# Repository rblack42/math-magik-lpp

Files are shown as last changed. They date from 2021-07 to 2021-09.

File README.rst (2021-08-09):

Math Magik LPP (v0.1.0)
#######################
:Author:    Roie R. Black
:Email:     roie.black@gmail.com
:Docs:      https://rblack42.github.io/math-magik-lpp

..  start-badges

.. list-table::
    :stub-columns: 1

    * - tests
      - | 



..  image:: rst/_static/lpp.gif
    :align: center
    :width: 600

.. end-badges

If you are visiting this link after reading my article *Designing an Indoor
Model Using OpenSCAD* in the 2021 edition of the NFFS Symposium, welcome!

This site is a work in progress. If you are interested in trying ano of this
project, please contact me at the email address above and I will be glad tro
provide assistance in getthing things running.

Here you will find updated documentation on building the *math-magik-lpp
*Limited Pennyplane* model, with corrections to equations and figures from the
symposium article.

More information on analyzing this model can be found on the companion website
at https://rblack42.github.io/math-magik

The project documentation is available at the link above. There you will find
material detailing the *OpenSCAD* code developed to support this project.

All code, both *OpenSCAD* and Python code, can be found on my github account:

    * https://github.com/rblack42/math-magik
    * https://github.com/rblack42/math-magik-lpp

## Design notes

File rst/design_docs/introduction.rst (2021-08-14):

Introduction
************

In this section you fill find listings of all |OSC| code used to generate the
|MM| |LPP| model. All documentation pages were generated automatically from the
current code in this project.

This documentation includes code blocks showing the actual |OSC| code created
for this model.

..	note::

    You *could* copy and paste these code blocks directly from these web pages,
    but that would be silly. Instead, go to the project site on |GH|_ and you
    can see everything I have generated for this project, uncluding the |OSC|
    code and supporting |PY| code.

The design code documentation is organized in the same way as the |OSC| files
themselves. Each part or assembly has its own directory and there is one
documentation page describing all of the files within that directory. The
pattern of the documentation is described below.

File Naming Convention
======================

I am using a simple naming convention for this project. All files used by |OSC|
to generate the complete model end with a **.scad** extension. Each part of
assembly is defined within a directory with that part or assembly name. Inside
that directory you will find a file with the same name as the directory, and
the **.scad** extension. This design file can be loaded into |OSC| and it will
generate that part or assembly for you to examine.

If and dimensions are needed to create a component, thse data values will be
located in files with names that look like this: **name_data.scad**. There are
two data files that do not follow this convention, both in the tip level code
directory: **constraints.scad** defines dimensions from the AMA rules for this
class, and **materials.scad** contains basic material dimensions.used in the
design.

Finally, positioning data needed t properly place each part or assembly in a
larger assembly are named with a pattern that looks like this:
**name_pos.scad**.

Design Notes
============

Information needed to describe how this component was designed will be
presented here.

Design File
===========

The code for the part or assembly is shown here. The caption at the top of each
listing indicates where in the actual code directory tree this file can be
located.

Data Files
==========

If data is needed to create this component, the data files used are shown next.
These files *include* other |OSC| files as needed to fully define all values
defined.

Components
==========

Assemblies gather other components together to create a larger component. In
the design file, we *use* these component files so we can refer to the needed
part or assembly. These will be placed properly using position data shown in
the next section. (This section will not be present for part documentation).

The list of components needed for the current assembly is shown as links that
will take you to the documentation for that component.

Component Position Data
=======================

All components needed to create the current assembly need to be oriented
properly in the new assembly's coordinate system. I created a simple **align**
function that will place each component using translations and rotations as
needed. The position data for each component is a vector with six values, three
for translations, and three for rotations. (This section will not be present
for part documentation)

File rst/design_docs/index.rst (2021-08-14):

assembly: math_magik_lpp
########################

..  include::  design_notes.rst

assembly Design File
********************

..  literalinclude::  ../../scad/math_magik_lpp.scad
    :linenos:
    :caption: math_magik_lpp.scad

Component Data File(s)
**********************

..  literalinclude::  ../../scad/math_magik_lpp_data.scad
    :linenos:
    :caption: math_magik_lpp_data.scad

..  literalinclude::  ../../scad/constraints.scad
    :linenos:
    :caption: constraints.scad

..  literalinclude::  ../../scad/materials.scad
    :linenos:
    :caption: materials.scad

Components
**********

..  toctree::
    :maxdepth: 1

    prop/index
    stab/index
    fuselage/index
    rubber_motor/index
    wing/index

Component Position File
***********************

..  literalinclude::  ../../scad/math_magik_lpp_pos.scad
    :linenos:
    :caption: math_magik_lpp_pos.scad

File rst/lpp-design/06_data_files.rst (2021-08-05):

Data Files
##########

We need to define dimensions for all the parts that make up the model. We also
need to define placement values that place each part or assembly in the proper
position in the model. Using |OSC|, we will define parts individually, then
assemble parts into assemblies. These may be further combined to produce the
final model. Al l of that means we need to set up these constants and do some
calculations to get things right.

Rather than place dimensions directly in the files where they are needed, I
elected to factor them out into separate data files that get included as
needed. The scheme I came up with to organize these data files is outlined
here.

Part Data Files
***************

Within each part directory (no subdirectories in these), the part data file
contains values needed to create the part. These data files may include other
data files as needed to fully define the part. For that reason, all data items
include the part name to avois conflicts in other places.

Assembly Data Files
*******************

When combining parts (or other assemblies) we need data that helps properly
place all components to create the assembly. Data needed for assemblies is
located in an assembly data file.

Position Data Files
*******************

In order to facilitate design analysis, all positioning data items are located
in position data files. These are only located in assembly directories.

Naming Data
***********

All data items have a distinct name. As much as possible, no "bare" numbers
should be found in shape design files. Instead, we include the necessary data
files to create each component.

Hopefully, changes to the design can be made by adjusting data item values.
Changes in the shape design files should not be needed, unless you are changing
that shape in some fundamental way.

Data Catalog
************

..	todo::

    Add a catalog of all defined data. This will be generated using a Python
    script that scans all data files.

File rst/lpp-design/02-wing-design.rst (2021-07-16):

Wing Design
###########

I decided to make this wing fairly simple. Basically it uses a constant chord
with rounded tips. The wing uses a conventional flat center section, with the
tips raised to provide the needed stability. Here is the general layout:

..  tikz::
    :libs:  arrows, calc

    \draw[ultra thick]  (0,0) -- (8,0) -- (8,3);
    \draw[ultra thick]  (8,3) arc[
    start angle=0,
    end angle=90,
    x radius=2,
    y radius=2] -- (0,5);

    \draw[thin] (0,5) -- (0,5.5) node[above] {$ c_l $};
    \draw[thin] (0,0) -- (0,5);
    \draw[thin,->] (0,0) -- (0,-0.5) node [below] {$x$};

    \draw[thin] (4,5) -- (4,0) node[below] {$y_t$};

    \draw[thin] (6,5) -- (6,0) node[below] {$y_a$};
    \draw[thin] (6,3) -- (8,3);
    \draw[thin,->] (8,0) -- (8.5,0) node[right] {$y$};

    \draw[thin] (0,0) -- (-0.5,0);
    \draw[thin] (0,5) -- (-0.5,5);
    \draw[thin,<->] (-0.25,0) -- node[left] {$C$}(-0.25,5);

    \draw[thin,->] (6,3) --node[above left] {$r_t$}  +(45:2);

    \draw[thin] (8,3.5) -- (8,5.5);
    \draw[thin, <->] (0,5.25) -- node[above] {$S/2$}(8,5.25);

The center section is a simple rectangular structure with a constant chord. The
span of this section is a design decision. Setting this dimension will have an
effect on the span of the tips, since the total projected wing span is fixed by
the rule constraints. I decoded to set up the dimensions for the center section
in a data file that will be placed in a **wing** subdirectory under the main
design directory

..  literalinclude::    ../../scad/wing/wing_data.scad
    :language: c
    :caption:   math-magik-lpp/scad/wing/wing_data.scad
    :linenos:

Notice that we *include* the **constraints.data** file so we can refer to
constants defined there. The path to that file shows that it is in the
directory above the **wing** directory (the main design directory).

For reference, here are the named constants we are using and the symbols from
the figure above:

..  csv-table::
    :header: constant, figure

    center_span, :math:`2 * y_t`
    chord, :math:`c`
    tip_radius, :math:`r_t`

Wing Ribs
*********

I decided to use a simple circular arc airfoil for this design. The arc is
defined by specifying the *camber* as a percentage of the chord. Figuring out
the actual arc radius involves a bit of math, byyt a nice Python tool called
*SymPy* makes this pretty easy (see the appendix for details). The formula for
the arc is given below:

..  math::

    r = \frac{c^2}{8t} + \frac{t}{2}

Where :math:`c` is the airfoil chord, and :math:`t` is the thickness. This last
value is simply calculated form the chord and camber (:math:`T`):

..  math::

    t = \frac{Tc}{100}

There are two ways to build this rib. One way involves bending a strip of wood
over a form to produce the rib. The second way uses a template to cut the rib
out of sheet stock. In the first case, there is a problem you might not notice
in building a real airplane. Suppose you want to make the front and rear spars
out of simple square stock, and you want to mage the rib using the same size as
the spars. If you slice off the arc at the leading and trailing edges, the
height of the rib at both points is actually larger than the spar sizes. This
is easy to see using |OSC|, which led me to use the template approach.

If you use a template, the arc is used to make a first cut, then the template
is slid down by the spar size and a second cut produces a rib with exactly the
right height on both ends. The problem is finding a way to create this rib
using |OSC| code.

Template Rib Library Module
===========================

I ended up using the *linear extrude* feature of |OSC| to create a general rib
shape. This |OSC| *module* is our first *library module*. The parameters of
this module allow us to create ribs as needed for any design.

The outline of the rib is a 2D figure produced using the above formulas to
calculate the radius of the arc we need. The outline is formed by creating two
circles, shifted by the height of the rib. These circles are trimmed using 2D
square shapes.  Finally the outline is extruded to generate the 3D rib.

..  literalinclude::    ../../MMlib/circle_template_rib.scad
    :language: c
    :caption: MMlib/circle-template-rib.scad
    :linenos:

This is a bit scary on first look, but line by line it should make sense. The
|OSC| *module* is a reusable chunk of code we will need when generating our
actual ribs. The parameters we need to supply are these:

    * chord - the trimmed length of the rib (not including the spars)
    * camber - the thickness as a percentage of the chord
    * height - basically the height of the leading and trailing edge spars
    * thickness - the thickness of the sheet we will use to form the ribs

Notice that there is code after the *module8 definition that serves to display
the shape if we load this *library module* file in |OSC|. This code will not be
run when we generate actual ribs using this module. This technique is handy
when debugging code.

It is important to note the position of the rib in the coordinate system. The
origin of this system is sitting in the center of the leading edge, with the
bottom of thr rib sitting on the **X-Y** plane. The rib is oriented so the
**Z** is "up". The **Z** axis runs through the center of the rib. We will need
this information when we place ribs in the actual design.

Generating Wing Ribs
====================

Now, we can create a rib *module* for wing ribs. All we need to do here is set
the correct values for the parameters:

..  literalinclude::    ../../scad/wing/center/rib/rib.scad
    :language: c
    :caption:   math-magik-lpp/wing/center/rib/rib.scad
    :linenos:

We will use five of these ribs, each properly positioned to form the wing
center section.

Here is the basic rib shape, ready for placement in the wing:

..  figure:: wing-rib.png
    :align: center
    :width: 500

Leading and Trailing Edges
**************************

The leading and trailing edge spars are something of a letdown! They are simple
square spars of a defined length. Again, it is handy to generate a *library
module* for a basic square spar.

..  literalinclude::    ../../MMlib/square_spar.scad
    :language: c
    :caption:   MMlib/square_spar.scad
    :linenos:

The spars created using this module are centered along the **Y** axis, again
sitting on the **X-Y** plane. This will be convenient for assembling the wing
center section.

..  figure:: wing-spar.png
    :align: center
    :width: 500

Assembling the Center Section
*****************************

We have defined the parts needed to build the center section frame. All we need
to do is place the parts in the right positions. We will let |OSC| do the
calculations needed for this step.

We need to decide how to organize these parts before building this section. WHile it is possible to do this all in one file, doing the analytical work to predict the weight and balance data will be more difficult if we do that. Instead, I decided to create directories for each part, and set up placement data files that control where each part sits in the final model. Although this creates a lot of directories, it keeps things more organized as we generate additional files during the analysis phase.

For the wing center section, we will need eight new direcroties, five for the ribs, one each for leading and trailing edges, and a final one for the covering.

The ribs and spars are created using our library modulae. We will add a placement data file in each part directoriy that defines exactly where the part sits in the assembly we are creating.

..  note::

    This plaement is not where the part sits in the final model. We will move assemblies into place as we build the final model.

Let's look at the rib at the left side (pilot's view") of the center section.

..
..  literalinclude::    ../../scad/wing/center/center.scad
    :language: c
    :caption: wing/center/center.scad
    :linenos:

..  note::

    This code is set up to color the material. The **colors.scad** file
    containg a number of useful color definitions was found on the Internet,
    and I added a color for Balsa. The eliminates the ugly green color that is
    generated by default when |OSC| creates images.

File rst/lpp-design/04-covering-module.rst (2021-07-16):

Building the Covering Module
############################

The covering module will be constructed as a Python class, allowing for
different rib sections, and wing outlines. In time, this code will be extended
to cover a variety of models.

Here is our start:

..

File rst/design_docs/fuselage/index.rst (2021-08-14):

assembly: fuselage
##################

..  include::  design_notes.rst

assembly Design File
********************

..  literalinclude::  ../../../scad/fuselage/fuselage.scad
    :linenos:
    :caption: fuselage/fuselage.scad

Component Data File(s)
**********************

..  literalinclude::  ../../../scad/fuselage/fuselage_data.scad
    :linenos:
    :caption: fuselage/fuselage_data.scad

Components
**********

..  toctree::
    :maxdepth: 1

    rear_hook/index
    thrust_bearing/index
    fin/index
    tail_boom/index
    wing_post/index
    stab_post/index
    motor_stick/index

Component Position File
***********************

..  literalinclude::  ../../../scad/fuselage/fuselage_pos.scad
    :linenos:
    :caption: fuselage/fuselage_pos.scad

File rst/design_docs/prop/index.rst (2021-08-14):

assembly: prop
##############

..  include::  design_notes.rst

assembly Design File
********************

..  literalinclude::  ../../../scad/prop/prop.scad
    :linenos:
    :caption: prop/prop.scad

Component Data File(s)
**********************

..  literalinclude::  ../../../scad/prop/prop_data.scad
    :linenos:
    :caption: prop/prop_data.scad

Components
**********

..  toctree::
    :maxdepth: 1

    blade/index
    spar/index
    wire_shaft/index

Component Position File
***********************

..  literalinclude::  ../../../scad/prop/prop_pos.scad
    :linenos:
    :caption: prop/prop_pos.scad

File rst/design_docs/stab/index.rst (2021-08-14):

assembly: stab
##############

..  include::  design_notes.rst

assembly Design File
********************

..  literalinclude::  ../../../scad/stab/stab.scad
    :linenos:
    :caption: stab/stab.scad

Component Data File(s)
**********************

..  literalinclude::  ../../../scad/stab/stab_data.scad
    :linenos:
    :caption: stab/stab_data.scad

Components
**********

..  toctree::
    :maxdepth: 1

    center/index
    left_tip/index
    stab_mount/index
    right_tip/index

Component Position File
***********************

..  literalinclude::  ../../../scad/stab/stab_pos.scad
    :linenos:
    :caption: stab/stab_pos.scad

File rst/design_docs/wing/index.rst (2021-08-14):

assembly: wing
##############

..  include::  design_notes.rst

assembly Design File
********************

..  literalinclude::  ../../../scad/wing/wing.scad
    :linenos:
    :caption: wing/wing.scad

Component Data File(s)
**********************

..  literalinclude::  ../../../scad/wing/wing_data.scad
    :linenos:
    :caption: wing/wing_data.scad

Components
**********

..  toctree::
    :maxdepth: 1

    center/index
    left_tip/index
    right_tip/index
    Wing_mount/index

Component Position File
***********************

..  literalinclude::  ../../../scad/wing/wing_pos.scad
    :linenos:
    :caption: wing/wing_pos.scad

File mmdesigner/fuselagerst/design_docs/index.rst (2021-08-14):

assembly: fuselage
##################

This assembly is created with the following file:

..  literalinclude::  ../../scad/fuselage/fuselage.scad
    :linenos:
    :caption: fuselage/fuselage.scad

Component Data File(s)
**********************

..  literalinclude::  ../scad/fuselage/fuselage_data.scad

Components
**********

..  toctree::
    :maxdepth: 1

    rear_hook/index
    thrust_bearing/index
    fin/index
    tail_boom/index
    fin_post/index
    wing_post/index
    stab_post/index
    motor_stick/index

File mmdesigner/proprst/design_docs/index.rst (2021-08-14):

assembly: prop
##############

This assembly is created with the following file:

..  literalinclude::  ../../scad/prop/prop.scad
    :linenos:
    :caption: prop/prop.scad

Component Data File(s)
**********************

..  literalinclude::  ../scad/prop/prop_data.scad

Components
**********

..  toctree::
    :maxdepth: 1

    blade/index
    spar/index
    wire_shaft/index

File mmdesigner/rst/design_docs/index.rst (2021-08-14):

assembly: math_magik_lpp
########################

This assembly is created with the following file:

..  literalinclude::  scad/math_magik_lpp.scad
    :linenos:
    :caption: math_magik_lpp.scad

Component Data File(s)
**********************

..  literalinclude::  ../scad/math_magik_lpp_data.scad

..  literalinclude::  ../scad/constraints.scad

..  literalinclude::  ../scad/materials.scad

Components
**********

..  toctree::
    :maxdepth: 1

    prop/index
    stab/index
    fuselage/index
    rubber_motor/index
    wing/index

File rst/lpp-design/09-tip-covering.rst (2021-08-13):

Tip Covering Logic
##################

Covering the center section of the wing and stab is a snap. That covering is
actually a simple slice out of a very thin cylinder since we are using
circular arc airfoils. I chose the generate the points on a grid that covers
the center section and use the *Function Grapher* logic created by `Justin
lin`_ to generate the actual covering shape.

The tips are another matter. If we keep the outer ribs of the center section
vertical and raise the wing tip up to form the dihedral, the inner edge of the
tip covering is not a straight line. Mathematically, it is a piece of an ellipse
formed by cutting a cylinder with an angled plane. We can extract the
coordinates of the outer edge of the center section covering and use those points
as our starting point for the tip covering. However, we need to account for the
dihedral angle we will be using and adjust those points to find the correct
starting points for the tip covering. (Remember, there is no actual rib here.

Tip Airfoil
***********

The tip has no ribs, only the tip outline as a structure. If we cover an actual
model with this structure, something modelers typically do by building the wing
flat, then the covering assumes some shape other than out circular arc as we
move toward the tip. The actual height of this shape tapers off to zero as we
approach the tip.

Here is a basic diagram showing the tip design:

..  tikz::
    :libs: calc, intersections

    \makeatletter
    \newcommand{\gettikzxy}[3]{%
        \tikz@scan@one@point\pgfutil@firstofone#1\relax
        \edef#2{\the\pgf@x}%
        \edef#3{\the\pgf@y}%
    }
    \makeatother

    \coordinate (o) at (0,0); % name the origin
    \coordinate (le) at (5,5); % inner leading edge
    \coordinate (te) at (5,0); % inner trailing edge
    \coordinate (s) at (2,5); % start of rib arc
    \coordinate (c) at (2,3); % center of rib arc
    \coordinate (t) at (0,3);  % top of outer rib

    % draw dihedral angle
    \draw[thick] (te) -- (o) -- (t);
    \draw[thick] (s) -- (le);
    \draw[thick, name path=arc] (2,5) arc (90:180:2);
    \draw[thin] (t) --  (0,6);
    \draw[thin, name path=grid] (0,4.5) -- (5,4.5);
    \draw[thin] (t) -- (c);
    \path [name intersections={of=arc and grid, by=E}];
    \draw[black,fill] (E) circle [radius=0.05];
    \gettikzxy{(E)}{\dx}{\dy}
    \draw [thin] (E) -- (\dx,1.5);
    \draw[thin, ->] (3,5.5) -- (3,5);
    \draw[thin, ->] (3,4) node[below]{$x$} -- (3,4.5) ;
    \draw[thin, ->] (-0.25,2) -- (0,2);
    \draw[thin, <-] (\dx,2) -- (1.2,2) node [right] {$\delta$};
    \draw[thin] (2,3) -- node [left] {$r$} (E) node [above] {$p$};
    \draw [thin] (s) -- (-0.75,5);
    \draw[thin, <->] (-0.5,5) -- node [left] {$C$} (-0.5,0);
    \draw[thin] (-0.75,0) -- (0,0);

In this figure, we are going to pick points on the outer part of the tip, along
the arc and the outer tip rib, that represent the intersection of a vertical
plane parallel to the **Y** axis drawn from the inner tip rib points to the
outer tip structure. We calculate the **Y** offset of the tip at the
intersection ($\delta$ in the figure above) and draw a straight 3D line between
the inner point and this outer tip structure. We will distribute points along
this line using the number of points selected in the **Y** direction for our
grid.

Since there are no supporting ribs along the tip span, I am going to assume
that the covering can be modeled as a set of straight lines from a point on the
center section outer rib to the tip outline. The selected points on the outline
will be chosen so that these tip covering lines are all parallel to the wing
axis (**Y**). This is not "real" in any sense, but should look fine visually,
and give us something close to right in weight and balance calculations.
Furthermore, the tip covering grid will need involves far fewer data points
than we might need with other ideas.

It is important to note that there will be visual problems as the covering
approaches the circular arc. The generated covering uses straight lines between
data points, and that means the tip outline will not be covered correctly. The
fewer the points we set up in the chord wise direction, the worse things will
look.

iWe are generating the grid for our covering using evenly distributed points
along the span and chord. In that code **x**, and **y** range from zero to one
and must be scaled to determine physical values.

The equations needed for calculating the coordinates of our tip grid point
(point **p** in the figure) are given here:

..  math::

    x_p = x * C

    y_p = span - \delta

    z_p =  tip_spar_size

We can determine $\delta$ using the equation of the circular arc centered as
shown in the figure:

..  mathcode::
   import sympy

   x,r,delta,c = sympy.symbols('x r delta c')
   eq1 = (r - delta)**2 + (r - x)**2 - r**2
   sol = sympy.solve(eq1, delta)
   sol[0]

And here is an image showing the grid on the wing tip:

Virtual Tip Rib
***************

There is no physical rib at the tip inner line. Instead the covering attaches
to the outer center section rib. When the tip is placed in its final position,
raised up to form the dihedral, the inner most edge of the tip covering must be
trimmed off to join nicely. Actually, we can use those center section rib
elevation values to form the correct starting points for the tip covering. The
calculations are pretty simple:

..  math::

    x_0 = x_c

    y_y = - z_c \sin{\theta}

    z_o = z_c \cos{\theta}

Here, the **0** subscript refers to the tip coordinate values at the "virtual
starting rib point, and **c** refers to the point values on the outer center
section rib. $\theta$ is the dihedral angle.

Python Covering Code
********************

All of the calculations needed to generate covering grids are included in the
**Covering.py** code file. This code creates a **covering.scad** file that cna
be *included* in other |OSC| files to generate the actual covering surface.

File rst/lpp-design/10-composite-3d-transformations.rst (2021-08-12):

Composite 3D Transformations
############################

In calculating the center of gravity for our model, we need to track how the center of mass for a given part moves as we align it into an assembly, them aligh an assembly into the final model. Qw uaw simple translation and rotation transformations to get our parts aligned as we wish in our design.

Translation Transformations
***************************

Mathematically, we can describe any transformation by setting up a
*transformation matcix* and using that matrix to calculate the effect of a
translation transformation.

Suppose we want to translate a shape using these distances in each coordinate
direction: $D_x$, $D_y$, and $D_z$. If we define a point, $P_0$ using three
positions: $P_x$, $O_y$, and $P_z$, then the translated point can be defined using
matrix multiplication:

..	math::

	T_1 = \left[\begin{matrix}1&0&0&0\\
		0&1&0&0 \\
		0&0&1&0 \\
		D_x&D_y&D_z&1\end{matrix}\right]

The position is given using a vector:

..	math::

	P_0 = \left[\begin{matrix}P_x&P_y&P_z&1\end{matrix}\right]

Rotations
*********

First, we rotate arount the **x** axis by an angle $\theta$:

..  math::

	R_x = \left[\begin{matrix}1&0&0&0\\
		0&\cos{\theta}&\sin{\theta}&0 \\
		0&-\sin{\theta}&\cos{\theta}&0 \\
		0&0&0&1\end{matrix}\right]

	R_y = \left[\begin{matrix} \cos{\beta}&0&-\sin{\beta}&0\\
		0&1&0&0 \\
		\sin{\beta}&0&\cos{\beta}&0 \\
		0&0&0&1\end{matrix}\right]

	R_z = \left[\begin{matrix}\cos{\zeta}&-\sin{\zeta}&0&0\\
		\sin{\zeta}&\cos{\zeta}&0&0 \\
		0&0&1&0 \\
		0&0&0&1\end{matrix}\right]

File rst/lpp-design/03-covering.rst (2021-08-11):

Generating Covering
###################

Building the basic framework of an indoor model airplane with |OSC| is fairly
easy. Covering is another matter entirely. There is no simple way to generate a
thin film that covers flying surface frameworks using just |OSC|. We need to
take another approach.

Since we are using math to figure out a lot of this design, let's see what we
can do if we think this through.

STL Files
*********

|OSC| is a 3D solid modeling tool most often used in generating 3D printer
products. Part of that generation process involves converting the 3D objects
into |STL| files. These files are then post-processed to generate input data
files for the 3D printer. An |STL| file is a (long) list of triangles that
"wrap" the surface in question. These triangles are all connected in such a way
that the surface is called water tight, meaning there are no gaps anywhere. If
the triangles are big, the surface will not resemble the original shape very
much, but if we make them tiny, he resulting surface will look very good. What
this means is that our entire model can be reduced to a giant list of triangles
surrounding the structure. The closer the points on these triangles are to each
other, the closer our approximation to the real shape gets.

Typically, indoor models are covered using a very thin film. Suppose we
generate a grid of points that sit on the surface we want to represent our
covering. The grid will represent a set of quadrilateral (four point) areas  on
that surface. We can draw a diagonal across each quad surface to produce two
triangles. Then we "extrude" these upward a tiny amount to represent a chunk of
film.This is exactly what an |STL| file looks like.

The thickness of the film is not important here. We only need it to be thick
enough to be visible in |OSC|. Traditionally, film weights are given in terms
of surface area, not volume. As long as we know what thickness we have set up
for our digital film, we can transform the volume we calculate for our covering
into a surface area and get the weight we need to weight and balance
calculations.

Function Grapher
****************

Suppose you can build a mathematical function describing the covering surface
you need:

..	math::

	Surface height = f(x,y)

Our challenge is to create a two-dimensional matrix of points covering each
segment of a flying surface. The surface function will tell us the height of
the surface at each point. Each point will be recorded using the **X**, **Y**,
and **Z** (height) values for the covering surface.  Python can write these
points out so that |OSC| can read the file produced.  Sounds simple enough for
a Python programmer.

`Justin Lin`_ created a tool for displaying a 3D function, input as a
collection of 3D points, using the **polyhedron** tool in |OSC|. His function
takes the rectangular array of 3D *X-Y-Z* points and extrudes them to create a
surface with a user defined thickness in the **Z** direction. Justin has a
library that uses this scheme on his website, and I started off by extracting
just part of that his for use in this project. This scheme is suitable for
indoor models, but will not work for more general model building, so I plan on
replacing this code at a later time.

Generating Covering Points
**************************

The challenge in using this approach is generating the matrix of points. I
elected to do this work in Python, and created a function that generates the
needed point array we can use for the covering.

The basic scheme used involved nested loops that create the grid. If we have **nx** points in the **X** direction, and **ny** points in the **Y** idirection, the loop setup looks like this:

..  code-block::    python

    dx = chord / nx
    dy = span / ny
    points = []
    for i in range(ny+1):
        y = i * dy
        xpoints = []
        for j in range(nx+1):
            x = j * dx
            z = surface_height(x,y)
            xpoints.append([x,y,z])
        points.append(xpoints)

Here, we are creating our surface data matrix as a "list of lists", which is
how you do this in Python.

Let's look at the rib height function we will use for the wing and stab center
sections.

Rib Height
==========

Here is our basic geometry:

..  tikz::
    :libs:  arrows, calc

    \draw(0,0) -- (7,0);
    \draw[thick](3.5,0) -> node[above] {r} ++(45:2.5) coordinate (p1);
    \draw(3.5,0) -- ++(135:2.5) coordinate (p2);
    \draw(3.5,0) -- (3.5,3);
    \draw[ultra thick] (p1) arc (45:135:2.5);
    \draw (4.5,0) arc (0:45:1);
    \draw (p1) -- (p2);
    \node[right] at (p1) {te};
    \node[left] at (p2) {le};
    \coordinate (angle_label) at ($ (3.5,0) + (22.5:1.2) $);
    \node at (angle_label) {$\alpha$};
    \coordinate (p3) at ($(p1) + (0,1.5) $);
    \coordinate (p4) at ($ (p2) + (0,1.5) $);
    \draw[<->] (p3) -- node[above] {C} (p4);

From this figure, we can generate two equations:

..  math::

    t = r - r sin(\alpha)

    C = 2 r cos(\alpha)

Here **C** is the rib chord and **t** is the rib thickness. We need to figure
out the radius, **r** and the angle :math`\alpha`.

Rather than doing this manually, let's introduce Python SymPy_, a neat tool you
wish you had back in your school days.

Here is a piece of code that will give up the results we are after:

..  code-block:: python

   import sympy

    r,c,t,alpha = \
      sympy.symbols('r c t alpha')

    eq1 = 2 * r * sympy.cos(alpha) - c
    eq2 = r - r * sympy.sin(alpha) - t
    sol = sympy.solve([eq1,eq2],[r,alpha])
    print(sol)

SymPy_ requires that you name your equations, and set them up as expressions
that evaluate to zero. So we move the left-hand side of each equation over to
the right and come up with some usable name.

The neat feature is the line where we solve these two equations for the two
unknowns. SymPy_ will produce the solutions we are after!

Here they are, nicely formatted:

..  mathcode::

    import sympy
    r,c,t,alpha = \
      sympy.symbols('r c t alpha')

    eq1 = 2 * r * sympy.cos(alpha) - c
    eq2 = r - r * sympy.sin(alpha) - t
    sol = sympy.solve([eq1,eq2],[r,alpha])
    sol[1]

The first solution gives us the arc radius, the second on gives :math:`\alpha`.

Let's check these equations out with a little Python code.

..  code-block::    python

    import math

    c = 5.0       # chord
    camber = 5.0  # percent of c

    t = camber * c
    r = c**2/(8*t) + t/2
    alpha = math.acos(4*c*t'(c**2 + 4*t**2)) * 180.0/math.pi
    print(r, alpha)

Here is what we get:

..  mathcode::

    import math

    c = 5.0       # chord
    camber = 5.0  # percent of c

    t = camber * c
    r = c**2/(8*t) + t/2
    alpha = math.acos(4*c*t/(c**2 + 4*t**2)) * 180/math.pi
    (r,alpha)

As  check, let's calculate the thickness using these values:

..  code-block:: python

    thickness = r - r * math.sin(alpha * math.pi/180.0)
    print(thickness)

..  mathcode::

    thickness = r - r * math.sin(alpha * math.pi/180.0)
    thickness

That is what we expect, so things look fine.

Rib Height
==========

To generate the height function needed to create our covering data array, we
need a bit of geometry. Since we are using a circular arc airfoil, the figure
below show basically what we need to generate the function:

..  tikz::
    :libs:  arrows, calc

    \newcommand{\tikzAngleOfLine}{\tikz@AngleOfLine}
    \def\tikz@AngleOfLine(#1)(#2)#3{%
    \pgfmathanglebetweenpoints{%
    \pgfpointanchor{#1}{center}}{%
    \pgfpointanchor{#2}{center}}
    \pgfmathsetmacro{#3}{\pgfmathresult}%
    }

    \coordinate (o) at (0,0);
    \coordinate (c) at ($(o)+(-45:2)$);
    \coordinate (e) at ($(c)+(45:2)$);
    \coordinate (t) at ($(c)+(67.5:2)$);
    \coordinate (p) at ($(c)+(67.5,2)$);
    \coordinate (m) at ($(o)!0.5!(e)$);
    \coordinate (c1) at ($(o)+(0,1.5)$);
    \coordinate (c2) at ($(e)+(0,1.5)$);
    \coordinate (c3) at ($(e)+(0,1.25)$);
    \coordinate (m2) at ($(t)+(3,0)$);

    \tikzAngleOfLine(c)(o){\AngleStart}
    \tikzAngleOfLine(c)(t){\AngleEnd}
    \draw[<->] (c)+(\AngleStart:1cm) arc (\AngleStart:\AngleEnd:1 cm);
    \node at ($(c)+({(\AngleStart+\AngleEnd)/2}:0.75 cm)$) {$\beta$};

    \draw[thin] (o) -- node[below left] {$r$} (c) -- (e) -- cycle;
    \draw [ultra thick] (o) arc (135:45:2);
    \draw[thin,->] (e) -- +(1,0) node[right] {$x$};
    \draw[thin,->] (o) -- (0,2) node [above] {$z$};
    %\draw[thick,->] (m) -- (t) node[above] {$z_c$};
    %\draw[thick,->] (o) -- node[above right=0.05] {$x_c$} (m);
    \draw[thin, dotted] (c) -- (t) node[above] {$p$};
    \draw[thin] (e) -- (c2);
    \draw[thin,<->] (0,1.25) -- node[above] {$C$}(c3);
    \draw[thin] (t) -- (m2);
    %\draw[thin,<->] ($(e)+(0.5,0)$)-- node[left] {$t$} +($(t)-(m)$);

The height of the rib at some point :math:`P` is given as follows:

Given a camber, chord, and radius, we can come up with the following equations:

..  math::

    t = camber \frac{C}{100}

    w = \frac{C}{2}

    h = t - r

    r^2 = (x - w)^2 + (z - h)^2

That last equation is the general equation for a circle centered at
:math:`(w,y)`.  We need to solve these equations for the height, :math:`z`.
SymPy_ to the rescue!

For some specified :math:`x, r, w, and h` we want to find the height,
:math:`z`: SymPy_ to the rescue!

..  code-block::    python

    import sympy

    x,z,h,w,r,c,t,beta = sympy.symbols('x z h w r c t beta')
    eq3 = (x-w)**2 + (z-h)**2 - r**2
    sol2 = sympy.solve(eq3, z)
    print(sol2[1])

..  mathcode::

    x,z,h,w,r,c,t,beta = sympy.symbols('x z h w r c t beta')
    eq3 = (x-w)**2 + (z-h)**2 - r**2
    sol2 = sympy.solve(eq3, z)
    sol2[1]

Let's make some substitutions. First, we eliminate :math:`w`:

..  code-block::    python

    eq4 = sol2[1]
    eq5 = eq4.subs(w,c/2)
    print(eq5)

..  mathcode::

    eq4 = sol2[1]
    eq5 = eq4.subs(w,c/2)
    eq5

Next, we eliminate :math:`h`:

..  code-block::    python

    eq6 = eq5.subs(h,t-r)
    print(eq6)

..  mathcode::

    eq6 = eq5.subs(h,t-r)
    eq6

Now we have an equation we can use to build our height function.

Here it is:

..  code-block::    python

    def rib_height(chord, camber, x):
        """return the height for some fraction of the chord x"""

        c = chord
        x = x * c
        t = camber * chord / 100
        r = chord**2/(8*t) + t/2
        return -r +t + math.sqrt((-c/2 + r + x)*(c/2 + r - x))

Let's test this out. The height at the midpoint should be the thickness:

..  code-block::    python

    print(rib_height(5,5,0.5))

..  mathcode::
    :newcontext:

    def rib_height(chord, camber, x):
        """return the height for some fraction of the chord x"""
        import math
        c = chord
        t = camber * chord / 100
        r = chord**2/(8*t) + t/2
        return -r + t + math.sqrt((-c/2 + r + x)*(c/2 + r - x))

    rib_height(5,5,0.5)

This gives us the height function needed for the circular arc airfoil. Next we
need to work on the wing outline.

Wing Outline
============

The wing is constructed using s rectangular center section and two rectangular
tip sections with a rounded leading edge. Here is the geometry we are using:

..  tikz::
   :libs:  arrows, calc

    \draw[ultra thick]  (0,0) -- (8,0) -- (8,3);
    \draw[ultra thick]  (8,3) arc[
    start angle=0,
    end angle=90,
    x radius=2,
    y radius=2] -- (0,5);

    \draw[thin] (0,5) -- (0,5.5);
    \draw[thin] (0,0) -- (0,5);
    \draw[thin,->] (0,0) -- (0,-0.5) node [below] {$x$};

    \draw[thin] (4,5) -- (4,0) node[below] {$y_t$};

    \draw[thin] (6,5) -- (6,0);
    \draw[thin] (6,3) -- (8,3);
    \draw[thin,->] (8,0) -- (8.5,0) node[right] {$y$};

    \draw[thin] (0,0) -- (-0.5,0);
    \draw[thin] (0,5) -- (-0.5,5);
    \draw[thin,<->] (-0.25,0) -- node[left] {$C$}(-0.25,5);

    \draw[thin,->] (6,3) --node[above left] {$r_t$}  +(45:2);

    \draw[thin] (8,3.5) -- (8,5.5);
    \draw[thin, <->] (0,5.25) -- node[above] {$S/2$}(8,5.25);

In this figure, we need to provide four parameters:

	* Which chord

	* Total wingspan

	* Center section span

	* Tip radius

..	note::

    In this figure, the total span is the flat span, not the span set by the
    rules. The rules ilmit the span with dihedral!

The leading edge offset, beginning where the circular section starts is defined
by another general circle equation. Let's consider a coordinate system
positioned at the start of the leading edge arc. Here is the equation for the
tip arc:

..  math::

    (x -r)^2 + y^2 = r^2

SymPy_ will give us our equation:

..  code-block:: python

    import sympy

    x,y,r = sympy.symbols('x y r')
    eq7 = (x-r)**2 + y**2 - r**2
    sol3 = sympy.solve(eq7, x)
    print(sol3[0])

..  mathcode::

    import sympy

    x,y,r = sympy.symbols('x y r')
    eq7 = (x-r)**2 + y**2 - r**2
    sol3 = sympy.solve(eq7, x)
    sol3[0]

This equation gives us the leading edge offset along the arc. A function that
gives us that offset for some percentage of the wing span looks like this:

..  code-block::    python

    def xle(s, r, y):
        """s is the half span, r is the tip radius and Y ranges from 0 to 1"""
        if y < s - r:
            return 0
        yt = y = (s - r)
        return r - math.sqrt((r-yt)*(r + yt))

We now have all the pieces needed to generate the covering for our model.

Covering grid
=============

As discussed earlier, we will generate the covering matrix by dividing up the
chord into **nx** points, and the span into **ny** points. Remember, we will be
generating covering shapes for each part of the model, not the assembled parts.

Wing and Stab Center Sections
-----------------------------

For the wing and stab, the grid is simple. We set up simple loops to generate
**X,Y** pairs, and use the height function to find the height.

..  note::

    There is a subtle point here. The ribs normally start at the inner edge of
    the leading edge and trailing edges. That means our airfoil is not really a
    pure circular arc. Rather than complicate things, I am gong to generate the
    covering as an arc, and position it so it connects to the leading and
    trailing edge outer points. Visually, this will be fine and the analysis
    will still be good. The covering will "float" above the actual framework a
    tiny amount.

Tip sections
------------

The tip sections are more of a puzzle. They will be canted upward to generate
the dihedral. Modelers normally build and cover the wings flat, and deal with
the covering at the joint using a variety of schemes. To make thing look proper
in |OSC| we need to do better.

Here is a look at the junction of two circular arc sections joined at some
dihedral angle:

..  image:: tip-joint.png
    :align: center
    :width: 400

If you look closely, the intersection is along a plane cutting through this
joint at an angle (one half of the dihedral). That means the end rib should
really be canted on the center section, something builders do not so.

Therefore, the joint we are going to create will not be a circular arc on the
tip, but a slight ellipse. The tip covering starts at the edge of yhe center
section, which we can calculate easily. There will be no rib at the inner edge
of the tip, but we can use the center section rib points, suitably transformed
to figure out the tip covering edge.

Phew!.

Here is the geometry we are dealing with:

..  tikz::

    \draw[thick] (0,0) -- (6,0) -- (9,1.75);
    \draw([thick] (0,0.25) -- (6,0.25) -- (9,1.75);

In this figure, we assume the tip covering runs in a straight line from the
center section to the flat tip rib. (Close enough for this study!)

But this means that our rib height function will not work for the tips. Instead, we need to use a straight line running from center section o the the tip and find the height of that line as needed. More math work!

Consider the general equation defining a line in 3D space:

Given two points in 3D space:

..  math::

    p1 = (x1,y1,z2)
    p2 = (x2,y2,z2)

Now, we define these constants:

..  math::

    l = (x2 - x1)
    m = (y2 - y1)
    n = (z2 - z1)

Then this equation defines the line:

..  math::

    (\frac{x - x1}{l} = \frac{y - y1}{m} = \frac{z - z1}{n}

If we set one coordinate value we can calculate the other two from this.

The only remaining problem is finding the set of points that represent the
inner edge of the tip covering surface. For this, we need to do a simple
transformation.

..  tikz::
    :libs:  arrows, calc

    \draw[thick]   (0,0) -- (3,0);
    \draw[thick] (0,1) -- (3,1) -- (3,0);
    \draw (3,0) -- (5,0);
    \draw (3,0) -- ++(30:2);
    \draw (3,1) -- ++(25:2);
    \draw (3,1) -- ++(-60:0.85);
    \draw[thick] (4,0) arc (0:30:1);
    \coordinate (angle_label) at ($ (3,0) + (15:1.2) $);
    \node at (angle_label) {$\theta$};

If the height of the rib at this edge is :math:`h_r`, then the length of the position along the tip leading edge is:

..  math::

    h_r \sin(\theta)

And the height of the tip covering at this point is:

..  math::

    h_r * \cos(\theta)

Now, finally we have all the pieces to write the covering module!

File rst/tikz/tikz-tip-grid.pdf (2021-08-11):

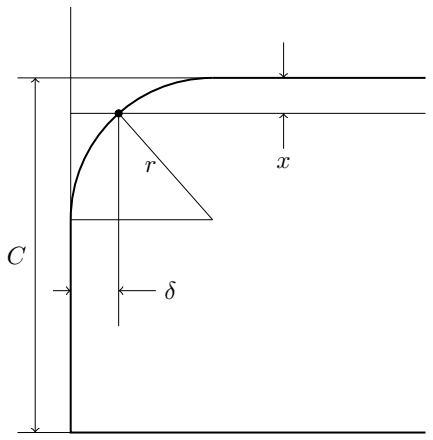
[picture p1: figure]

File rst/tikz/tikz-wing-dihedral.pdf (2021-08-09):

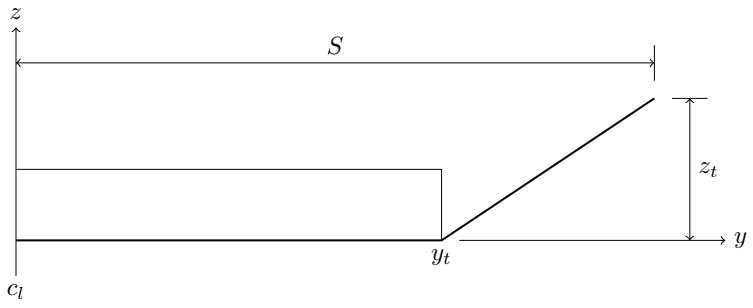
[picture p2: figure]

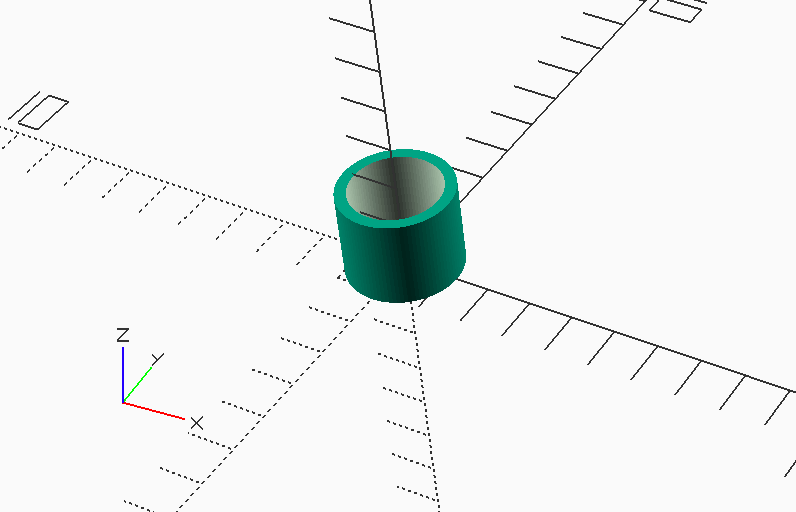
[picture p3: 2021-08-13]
docs/_images/paper_tube.png

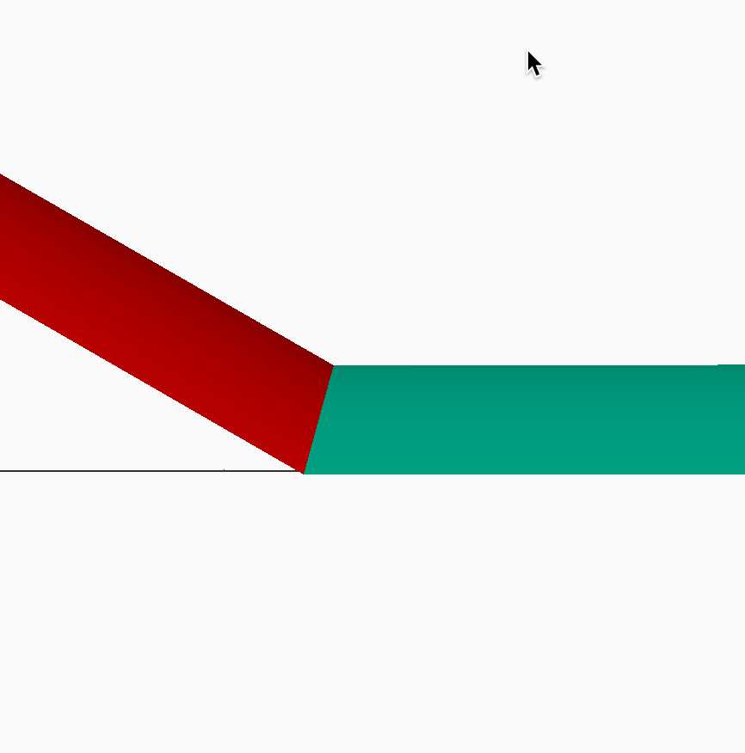
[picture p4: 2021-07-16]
rst/lpp-design/tip-joint.png

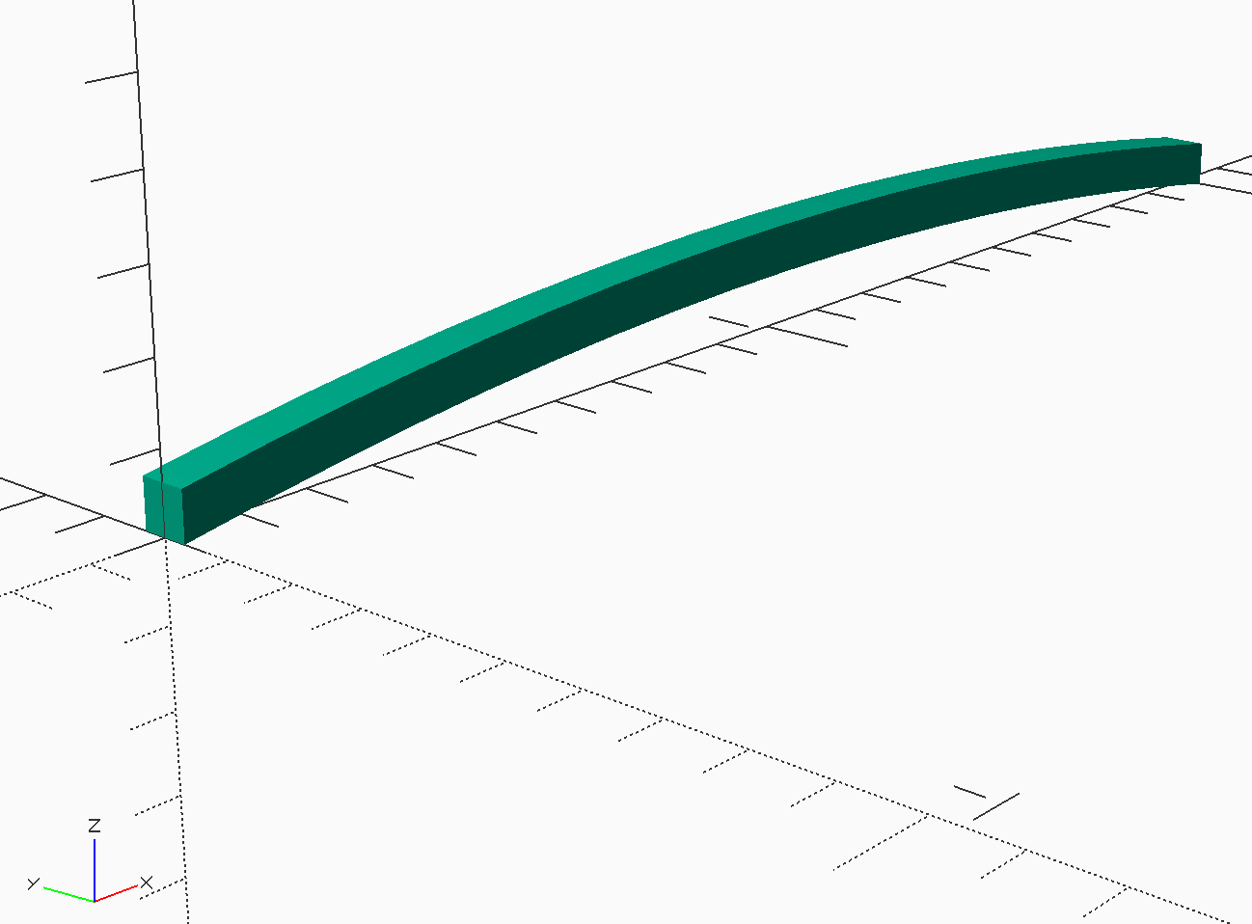
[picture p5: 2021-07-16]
rst/lpp-design/wing-rib.png

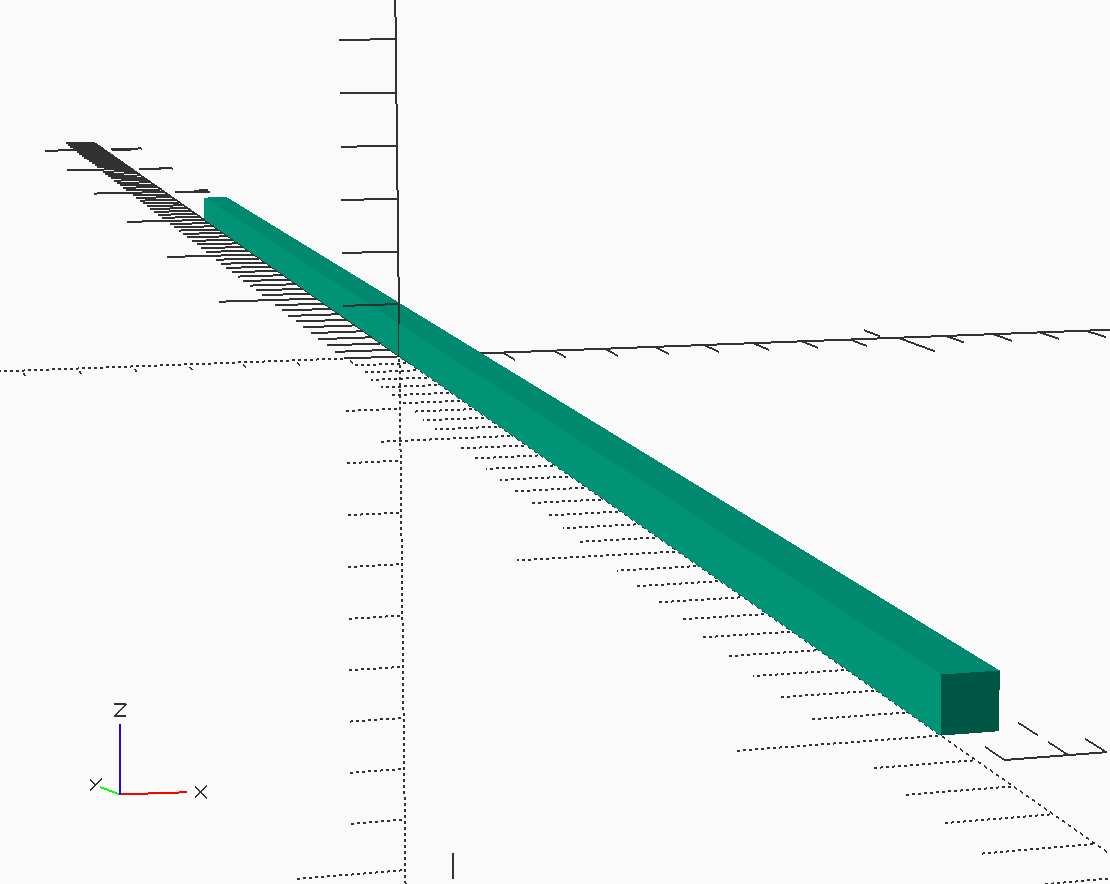
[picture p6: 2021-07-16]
rst/lpp-design/wing-spar.png

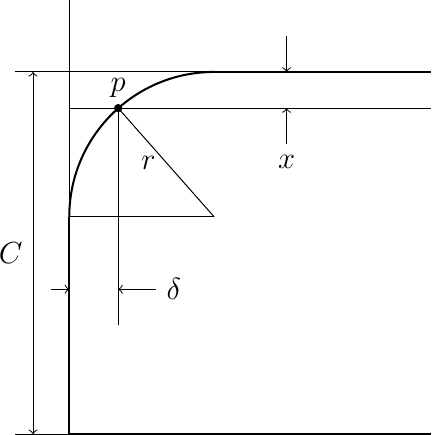
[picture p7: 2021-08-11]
docs/_images/tikz-ee8917caa3f110df39323bd53fd3d9d8a87862fa.png

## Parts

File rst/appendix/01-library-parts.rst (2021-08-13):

..  _library-parts:

Library Parts
#############

Several of the |OSC| code files developed are useful in other projects, so they
are collected into a library folder rather than just placing then in the
general model design folders. |OSC| supports loading files from user libraries
with a little setup. To do this, you must configure your system to add the
**OPENSCAD** environment variable so that the application can see this when you
start up |OSC|. Details can be found in the |OSC| documentation.

Colors
******

Here is a file listing available colors that can be used in generating the
visual representation of parts and assemblies. I added one color to represent
balsa wood. The original color file was created by *David Powell* and was found
in a post on the |OSC| forum at
https://forum.openscad.org/CSG-Difference-bogus-color-logic-td5265.html:

..  literalinclude::    ../../MMlib/colors.scad
    :linenos:
    :language: c

Positioning
***********

Since we need to position components many times during the building of the
final design, I created a simple routine that will translate and rotate
components for final placement in an assembly. This code uses a neat feature of
the |OSC| language that lets you apply a function to the code that follow this
one. The **align** function defined here significantly reduces the clutter of
the design code. The included **position** function applies translations only:

..  literalinclude::    ../../MMlib/position.scad
    :linenos:
    :language: c

Simple Spars
************

We use three basic spars in models: a straight square spar, a single tapered
spar, and a double tapered spar. Eventually, I will modify these routines to
allow for rectangular cross sections.

Square Spar
===========

..  literalinclude::    ../../MMlib/square_spar.scad
    :linenos:
    :language: c

..  image::     square_spar.png
    :align: center

Single Tapered Spar
===================

..  literalinclude::    ../../MMlib/single_taper_spar.scad
    :linenos:
    :language: c

..  image::     single_taper_spar.png
    :align: center

Double taper Spar
=================

..  literalinclude::    ../../MMlib/double_taper_spar.scad
    :linenos:
    :language: c

..  image::     double_taper_spar.png
    :align: center

Mounting Posts
**************

Indoor models are usually not glued together permanently. Instead, we use posts
and paper tubes to allow parts to be separated for transport.

Rounded Posts
=============

These are simple square pieces with a rounded top for the paper tube to slide
over.

..  literalinclude::    ../../MMlib/rounded_post.scad
    :linenos:
    :language: c
..  image::     rounded_post.png
    :align: center

Paper Tubes
===========

Paper tubes, formed by glueing tissue strips wound over a mandrel of some
sort are attached to structural parts and placed to slide over mounting posts.

..  literalinclude::    ../../MMlib/paper_tube.scad
    :linenos:
    :language: c

..  image::     paper_tube.png
    :align: center

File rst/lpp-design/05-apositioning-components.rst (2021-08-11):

Positioning Components
######################

One of the issues with designing with |OSC| is getting things positioned
correctly. In a traditional *CAD* program, you just drag things around and
things pop into place. Not so with |OSC|. You need to think through exactly where
things need to go, and that involves knowing exactly where the parts are
located in the coordinate system.

Coordinate Systems
******************

Every individual part and assembly is created in its own coordinate system.
When moving parts around, the part or assembly is translated and/or rotated
into the proper position within this coordinate system.

You are in charge of the system used to design any part or assembly! All of
this is a mental exercise. The important part of this process is being able to
mentally visualize the gadget you are about to design, then identify points
within that coordinate system that will be important in your design work. As
much as possible, I try to think about each component the way a builder thinks
and works. Most models are built on some kind of flat surface, so I make that
surface the **X-Y** plane, and place the part the origin of the coordinate
system. When assembling the model, I switch to a "pilot's" view of the world. I
place the origin of this system at some point on the front of the model and run
the **X** axis down the fuselage to the tail. The wings are aligned along the
**Y** axis, and the **Z** axis ends up aligned vertically .

For example, when designing an individual rib for an indoor model, I set up the
coordinate system with the origin located at bottom front of the leading edge
of the rib. The rib is constructed flat on the **X-Y** plane, and the lower
point on the rib sits flat on the **X-Z** plane.

When we use this rib in the wing assembly, the coordinate system is different.
For the wing, the leading and trailing edge spars should end up sitting on the
**X-Y** plane, and the wing is centered relative to the **X-Z** plane.

That means we need to position the rib within the wing's coordinate system.
That will involve rotating it so it is oriented correctly, then translating
that rib into its proper position within the wing structure.

..  note::

    Of course, there is the issue of properly trimming the rib sit it fits
    nicely against a wing spar. There are a lot of details modelers never think
    about while building. I am working on ideas to streamline a lot of these
    details as I work on this project!

Visualizing Components
======================

|OSC| make it easy to see the results of your work. You tweak the code, then
generate a display that shows the results. (Of course, you never make typos,
but if you do, you can fix then quickly!).

There is an interesting way to use |OSC| that I find handy.

I write a lot on my computer. Some of my writings are just normal text, some is
code. Long ago I settled on a nice editing tool called **vim** that I have used
for ll kinds of textual work. I really do not like working on some editing tool
that is not as smart as my favorite editor. Fortunately, |OSC| lets me write
code in my favorite editor, then save that work on my system. |OSC| can monitor
a file you are editing, and then it sees a saved change, it will automatically
regenerate your design so you can see it easily. That save a lot of time!

Using this scheme, I open up my favorite editor and |OSC| at the same time and
position the screen windows as i like. I then set up |OSC| to use this feature,
and turn off the |OSC| editor.

To do this,
The
critical point we need to remember is the location of the origin of the rib's

coordinate system (bottom of the leading edge, right in the middle of the rib).
That point must me moved into the proper position in the wing's coordinate
system. The translations need to slide the rib to the right spot, and any
rotations needed to properly align the rib need ot happen before moving.

Align Function
**************

To make this a bit easier, I wrote an *align* function that takes a list of six
values:

..	math::

	[x_y, y_t, z_t, x_r, y_r, z_r]

Using this function involves calculating exactly what translations and
rotations are needed to properly position that part. Since individual parts do
not need to be aligned (unless you need to do that to properly create the
part, I set up a file named *partname_pos.scad* within each assembly directory. This file lists the alignment values need to build the assembly out of the required components.

Using this concept, constructing an assembly is as simple as listing the
components and aligning each one:

..	literalinclude::	../../scad/wing/wing.scad
	:linenos:
	:language: c

Calculating Alignment Values
****************************

In setting up the alignment values, you need to access design values.
The dimensions of each component are important in figuring this out. There is
no easy to avoid needing to do some annoying calculations. For instance, when
positioning the wing posts on the side of the motor stick, we need to know how
thick the motor-stick is and how thick the wing posts are. The offset needed is
one half the sum of these two values:

..	code-block::

	post_x_offset = (motor_stick_thickness + wing_post_size)/2;

I have tried to name these dimensions to make it clear what the calculations
involve. Unfortunately, some calculations need access to dimensional values
defined in other directories. To make this a bit easier to manage, I am placing
a data file in each directory where these values are either defined, of
calculated as needed to define the component in the associated directory.

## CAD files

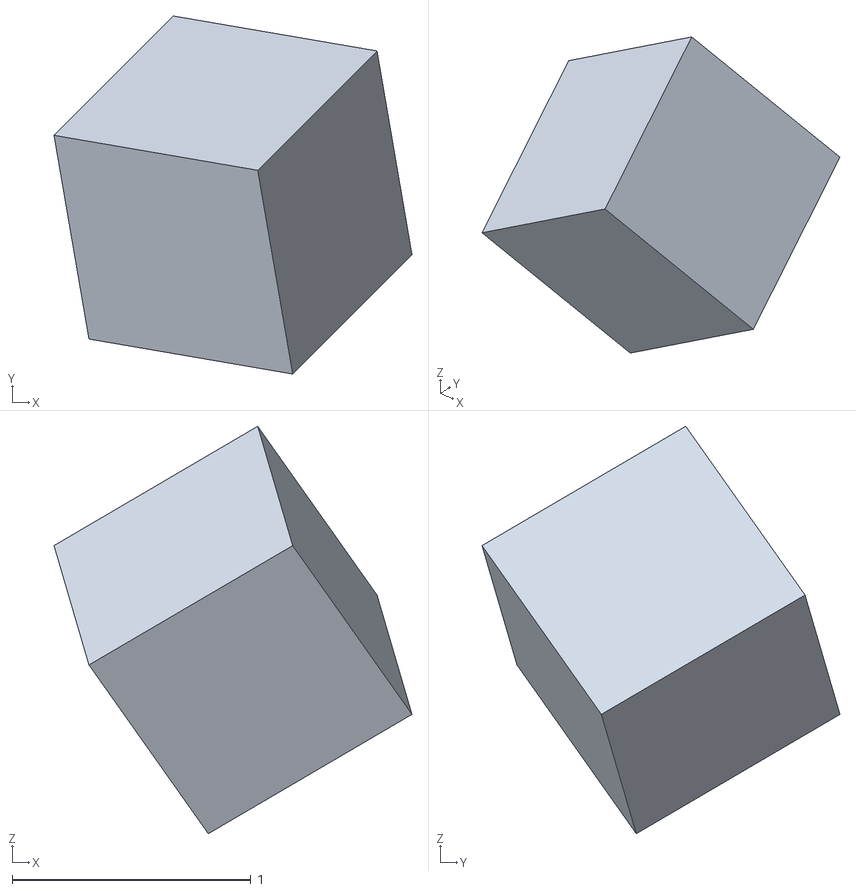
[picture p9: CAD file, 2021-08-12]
rst/references/basic-cube.stl
1.50 x 1.50 x 1.71

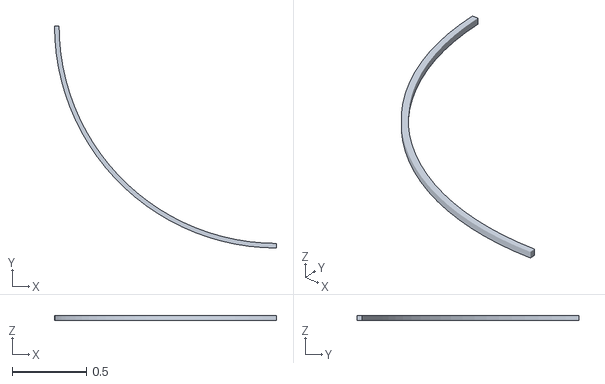
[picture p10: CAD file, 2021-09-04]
scad/math-magik-lpp/fuselage/fin/arc/arc.stl
1.50 x 1.50 x 0.0312

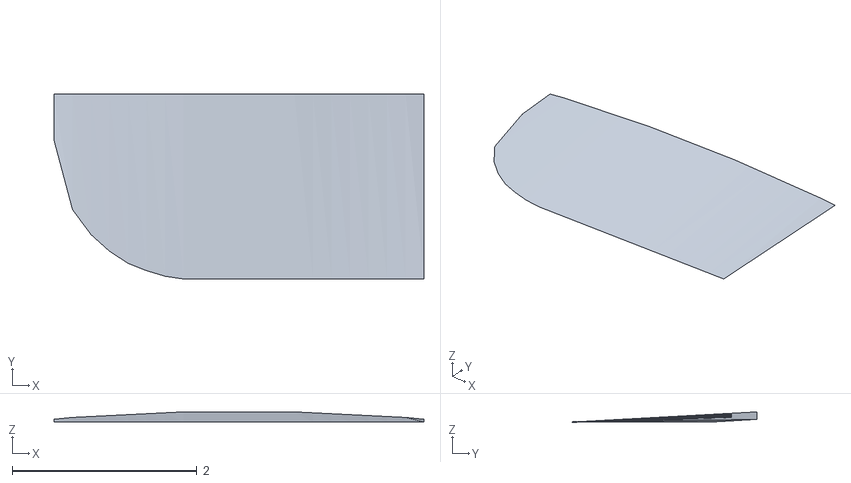
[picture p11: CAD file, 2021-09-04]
scad/math-magik-lpp/fuselage/fin/covering/covering.stl
4.00 x 2.00 x 0.111

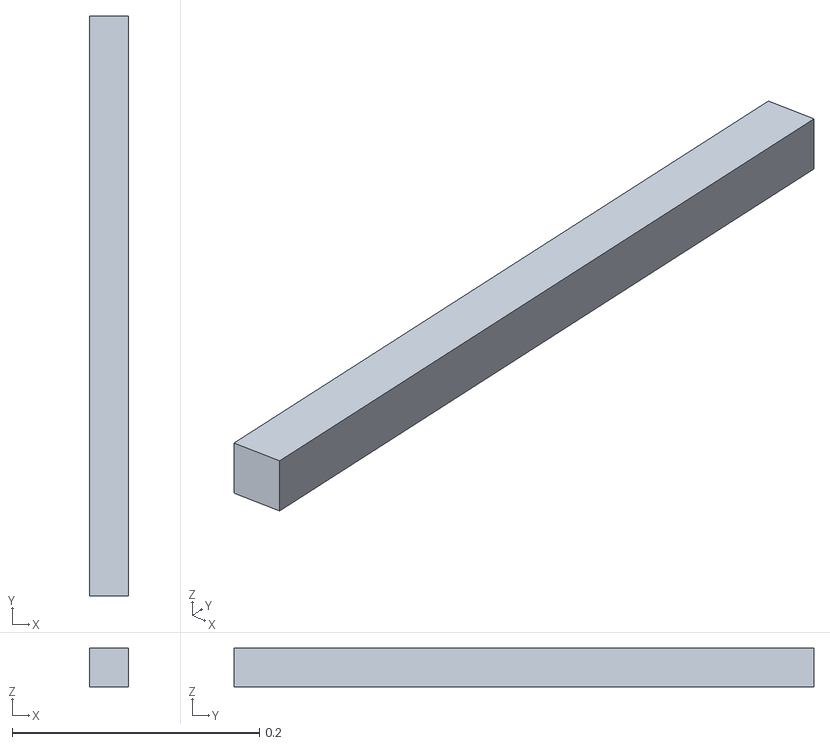
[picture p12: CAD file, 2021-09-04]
scad/math-magik-lpp/fuselage/fin/leading_edge/leading_edge.stl
0.0312 x 0.469 x 0.0312

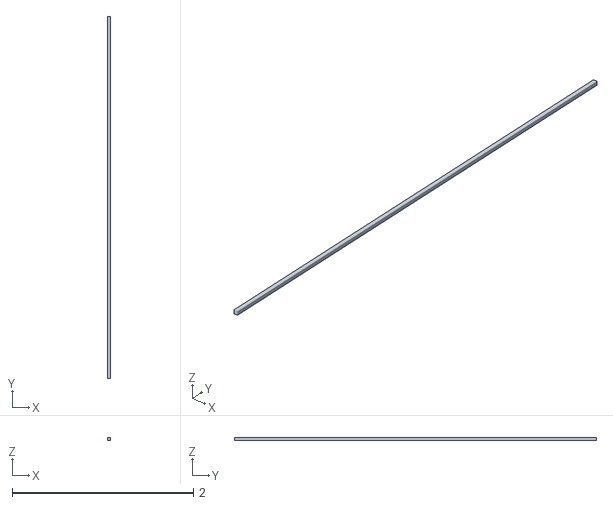
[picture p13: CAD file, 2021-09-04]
scad/math-magik-lpp/fuselage/fin/rib1/rib1.stl
0.0312 x 4.00 x 0.0312

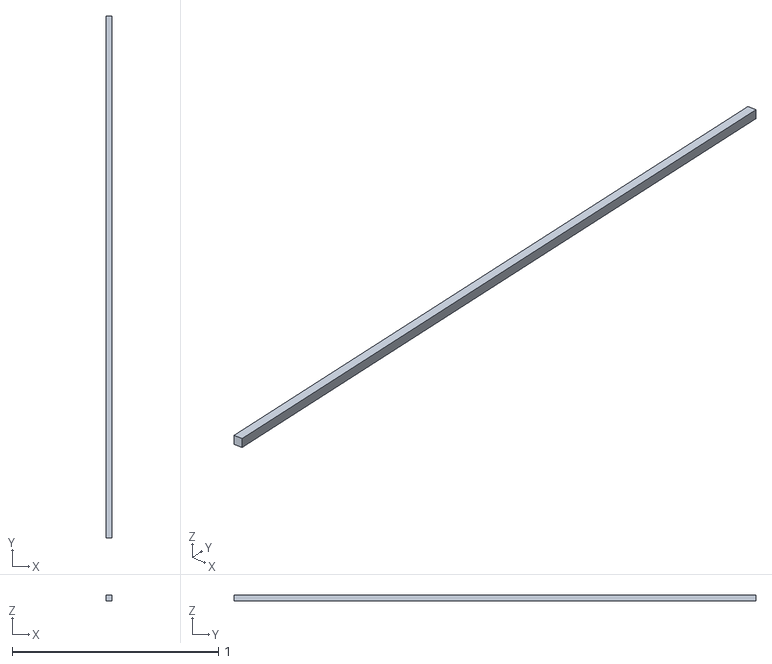
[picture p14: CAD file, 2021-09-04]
scad/math-magik-lpp/fuselage/fin/rib2/rib2.stl
0.0312 x 2.53 x 0.0312

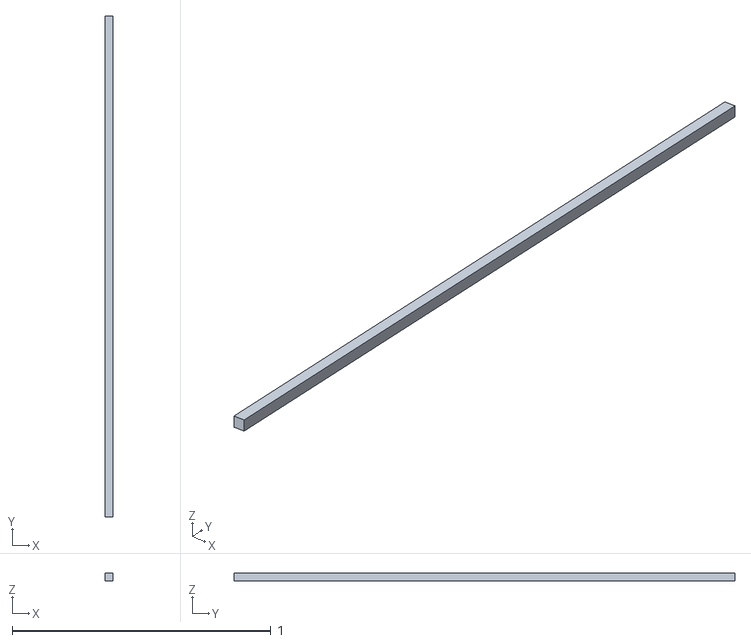
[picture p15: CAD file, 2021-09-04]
scad/math-magik-lpp/fuselage/fin/trailing_edge/trailing_edge.stl
0.0312 x 1.94 x 0.0312

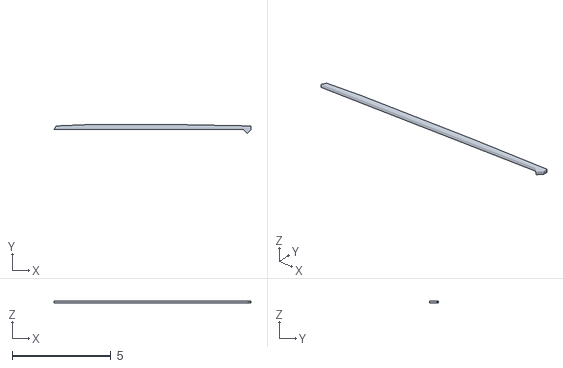
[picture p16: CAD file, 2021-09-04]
scad/math-magik-lpp/fuselage/motor_stick/motor_stick.stl
10.0 x 0.438 x 0.125

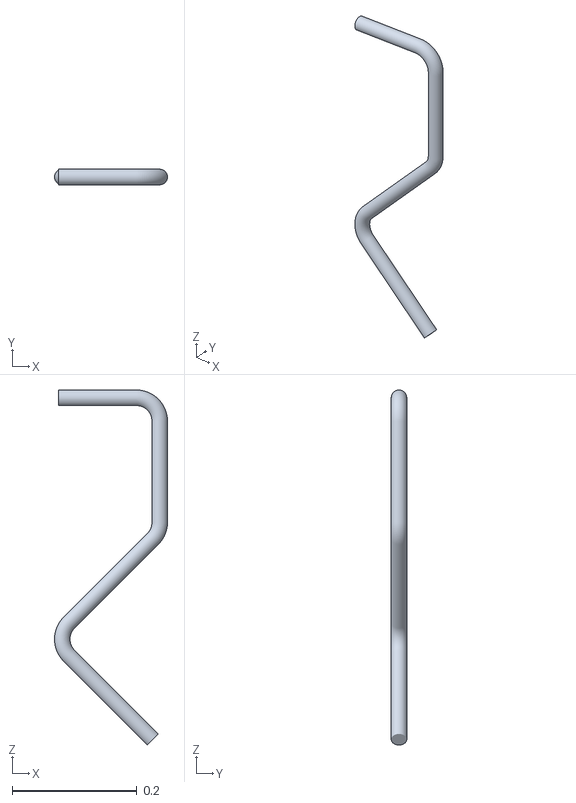
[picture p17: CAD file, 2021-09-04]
scad/math-magik-lpp/fuselage/rear_hook/rear_hook.stl
0.181 x 0.025 x 0.57

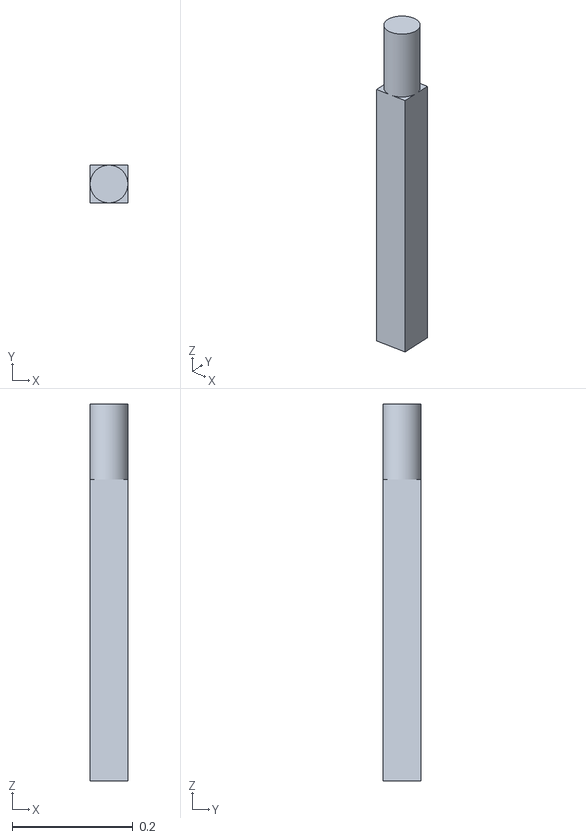
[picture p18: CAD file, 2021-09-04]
scad/math-magik-lpp/fuselage/stab_post/stab_post.stl
0.0625 x 0.0625 x 0.625

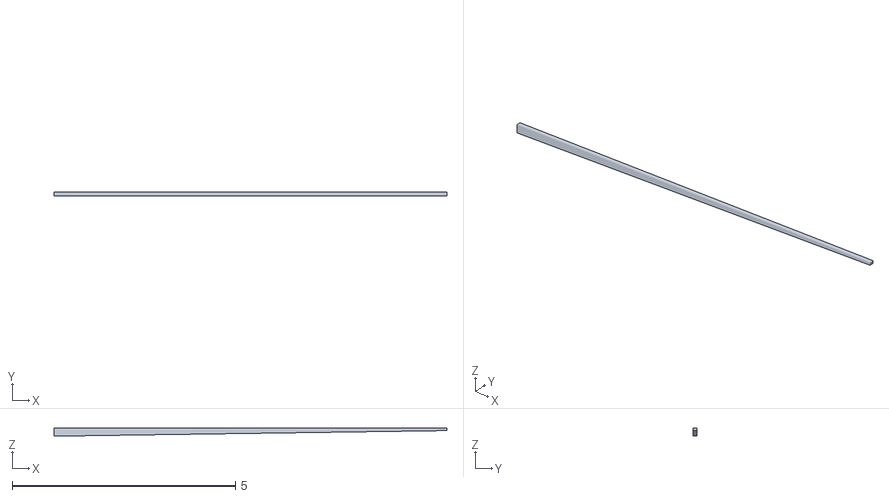
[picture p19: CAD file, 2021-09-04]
scad/math-magik-lpp/fuselage/tail_boom/tail_boom.stl
8.80 x 0.0938 x 0.188

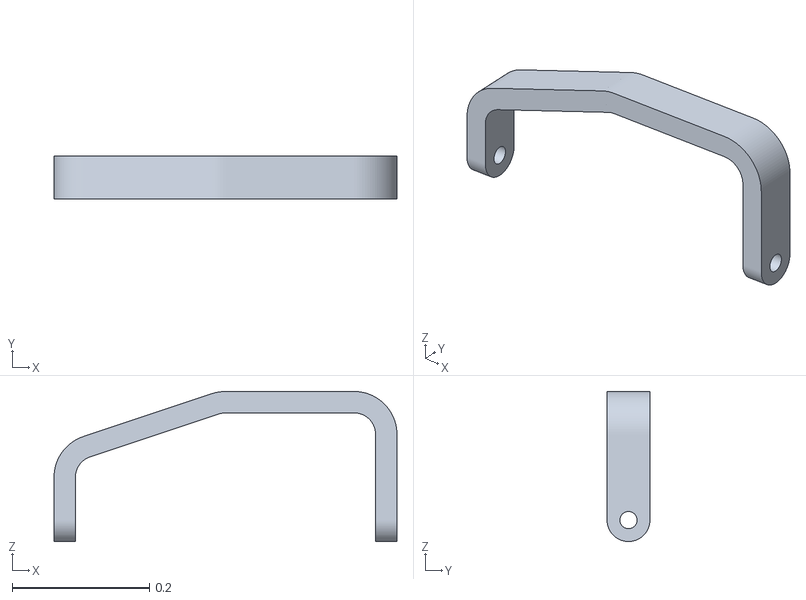
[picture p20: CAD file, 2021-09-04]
scad/math-magik-lpp/fuselage/thrust_bearing/thrust_bearing.stl
0.5 x 0.0625 x 0.219

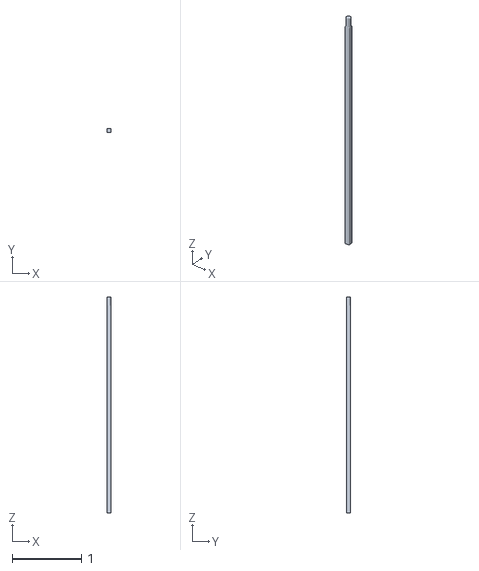
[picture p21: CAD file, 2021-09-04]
scad/math-magik-lpp/fuselage/wing_post/wing_post.stl
0.0625 x 0.0625 x 3.12

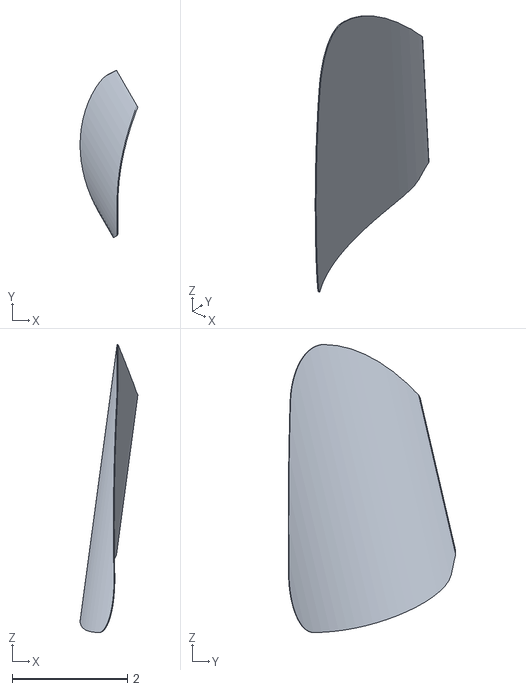
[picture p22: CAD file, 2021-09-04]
scad/math-magik-lpp/prop/blade/blade.stl
1.00 x 2.91 x 5.00

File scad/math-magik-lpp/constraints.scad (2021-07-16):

//####################################
// Math-Magik LPP - Design Constraints
// (c) 2021 by Roie R. Black
//====================================

// AMA Rules for event 208
//------------------------------------

max_overall_length = 20;
max_projected_wing_span = 18;
max_bearing_to_rear_hook = 10;
max_wing_chord = 5;
max_stab_span = 12;
max_stab_chord = 4;
max_prop_diameter = 12;

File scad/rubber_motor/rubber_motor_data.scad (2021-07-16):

//###################################################
// rubber_motor_data.scad - Math-Magik-LPP
// (c) 2021 by Roie R Black
//===================================================

rubber_motor_length = 10;
rubber_motor_radius = 1/8;

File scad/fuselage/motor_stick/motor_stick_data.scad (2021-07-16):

//#####################################
// motor-stick-data.scad
// (c) 2021 by Roie R. Black
//*************************************

ms_thickness = 1/8;
motor_stick_rear_height = 0.1875;
ms_length = 10;

ms_points = [
	[0,0],
	[9.625,0],
	[9.8125,-0.1875],
	[10.0,0],
	[10.0,0.1875],
	[6.625,0.25],
	[1.625,0.25],
	[0.10825,0.1875],
	[0,0]
];

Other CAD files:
scad/math-magik-lpp/prop/spar/spar.stl
scad/math-magik-lpp/rubber_motor/rubber_motor.stl
scad/math-magik-lpp/stab/center/covering/covering.stl
scad/math-magik-lpp/stab/center/rib/rib.stl
scad/math-magik-lpp/rubber_motor/rubber_motor.scad
MMlib/circle_strip.scad
MMlib/circle_template_rib.scad
MMlib/circular_arc_spar.scad
MMlib/circular_arc_strip.scad
MMlib/colors.scad
MMlib/covering_generator.scad
MMlib/double_taper_spar.scad
MMlib/elliptic_blade_blank.scad
MMlib/paper_tube.scad
MMlib/position.scad
MMlib/prop_bearing_2D.scad
MMlib/rounded_post.scad
MMlib/single_taper_spar.scad
MMlib/square_spar.scad
mmdesigner/fin_tip_cover_points.scad
mmdesigner/stab_center_cover_points.scad
mmdesigner/stab_tip_cover_points.scad
mmdesigner/wing_center_cover_points.scad
mmdesigner/wing_tip_cover_points.scad
scad/fuselage/fin/arc/fin_arc.scad
scad/fuselage/fin/covering/fin_covering.scad
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

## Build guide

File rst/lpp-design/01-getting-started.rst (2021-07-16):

Getting Started
***************

To get started on this project, you need to make sure you have |OSC| installed.
The project website has installers for all major platforms (Windows, Mac, and
Linux). For an overview of using this program, see the |MM| project
documentation. I highly recommend that you print out a copy of the |OSC| "cheat
sheet" available at https://openscad.org/cheatsheet

|LPP| Rules
***********

We cannot get much design work done without a clear understanding of the class
rules. These are published in the `AMA Rulebook`_ under "Event 208".

Basically, we need to respect a few model dimensions and weights in order to
compete in this class. All of these are specified in a single |OSC| data file
placed at the top of the model design directory:

..  literalinclude::    ../../scad/constraints.scad
    :language: c
    :caption:   math-magic-lpp/scad/constraints.scad
    :linenos:

Note that in this design, all dimensions are in inches. |OSC| supports doing
simple math when defining constants, so I am using things like **1/16** to
indicate a standard modeling dimension, rather than using the actual decimal
value.

Also note that I name data files with a **.data** extension. |OSC| will handle
these files just fine. All files with an **.scad** extension will define actual
model parts or assemblies.

Parts and Assemblies
********************

In this design, a *part* is a single component constructed out of some building
material. When we analyze the properties of a part, we will need to specify the
density of the material. In order to simplify the design, and set up useful
components that might be useful in other designs, some *part* code files will
be placed in a library folder. The *library parts* generally use parameters
that need to be set to construct an actual physical part. We will see this
concept in action soon in our design work.

An *assembly* is a collection of parts combined to form a higher level
component of the model. Assemblies can join simple parts, or other assemblies
as needed to complete the model.

|OSC| is generally used by folks building things using 3d printers. In those
applications, it is common to "fuse" parts together so generating files needed
by a 3D printer can be constructed. in our design work, we will not be doing
that. Instead, we need to carefully align parts so they end up placed in
exactly the right spot. Fortunately, you can do simple calculations in |OSC|
code to simplify this process.

Design Process
**************

In the pages that follow, we will work on model parts in no particular order.
We will initially focus on building a few parts, then set up assemblies that
use those parts. The last thing we will be doing is assembling the complete
model. This process is much the same as the one you would use to build any
model using real parts. There is not one "correct" way to do this, although
some things get pretty obvious.

In the next section, we will start off by building the wing.

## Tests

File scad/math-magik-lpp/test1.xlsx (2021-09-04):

part | maxx | minx | maxy | miny | maxz | minz | volume | density | weight | cgx | cgy | cgz | ixx | ixy | ixz | iyx | iyy | iyz | izx | izy | izz
/prop/blade/blade.json | 0.73941 | -0.264254 | 2.36252 | -0.545084 | 5.48296 | 0.482963 | 0.1916580415741104 | 4 | 0.2012373944 | 0.1613311736428545 | 0.7361832762661582 | 2.856741644364287 | 0.4271499239376415 | -0.0018663818364773321 | -0.03743585790564283 | -0.0018663818364773321 | 0.32578710569455027 | 0.014849514666591679 | -0.03743585790564283 | 0.014849514666591679 | 0.11621595635377013
/prop/spar/spar.json | 0.03125 | -0.0310993 | 0.03125 | -0.03125 | 2.0 | -2.0 | 0.007146790682327264 | 5 | 0.009379997336 | 3.405177202119859e-11 | 0.0 | 0.0 | 0.006535317047631165 | -0.0 | -0.0 | -0.0 | 0.006535317047615858 | 7.579122514774402e-14 | -0.0 | 7.579122514774402e-14 | 2.314314039001536e-06
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

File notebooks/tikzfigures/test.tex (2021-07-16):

\documentclass{standalone}
\usepackage{tikz}
\begin{document}
\usetikzlibrary{calc}
\begin{tikzpicture}
  \draw[thick] (0,0) -- (6,0) -- (9,1.75);
  \draw[thick] (0,0.25) -- (6,0.25) -- (9,1.75);
\end{tikzpicture}
\end{document}

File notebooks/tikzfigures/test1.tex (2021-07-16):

\documentclass[tikz]{standalone}
\begin{document}
\begin{tikzpicture}
\draw[help lines] grid (5, 5);
\draw[fill=black] (1, 1) rectangle (2, 2);
\draw (0,0) -- (4,4);
\end{tikzpicture}
\end{document}

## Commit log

2021-07-16 Adding code files describing eash component
    [blade.scad, center.scad, circle_strip.scad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]
2021-08-05 updates to design files
    [fin-covering.scad, fin-covering.stl, fin.scad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]
2021-08-09 adding covering
    [center.scad, cover-points.scad, covering.scad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]
2021-08-11 refactored covering logic
    [cover-points.scad, cover_points.scad, covering.scad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]
2021-08-12 aligned wing and stab on mounting posts
    [basic-cube.stl, cover_points.scad, fuselage_data.scad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]
2021-08-13 code file autodoc setup
    [cover-points.scad, covering.scad, fuselage_data.scad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]
2021-08-14 fix bug in prop location
    [fuselage_data.scad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]
2021-09-04 fixed fin name errors
    [arc.scad, arc.stl, arc_data.scad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]
